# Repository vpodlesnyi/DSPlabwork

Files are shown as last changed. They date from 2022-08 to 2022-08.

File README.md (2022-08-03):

# DSPlabwork
The PCB for Digital Signal Processing classes at the Department of Mechatronics and Robotics.

Technical specifications:
- signal processing from a strain gauge force sensor;
- signal processing from an electret microphone;
- I2C;
- sound generation;
- main MCU ATMega328.

demo image

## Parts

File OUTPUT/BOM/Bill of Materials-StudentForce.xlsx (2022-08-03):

Description | Part Number | Value | Voltage | Designator | Quantity
12-Bit DAC with SPI™ Interface | MCP4921-E/P |  |  | DD1 | 1
Cтабилитрон (лавинный выпрямительный диод) односторонний | SMAJ5.0A-TR |  |  | VD7 | 1
EMI Suppression Filter | BLM18PG181SN1D |  |  | L1 | 1
EMI Suppression Filter | SDR0604-2R2ML | 2,2мкГн |  | L2 | 1
EMI Suppression Filter | CM201212-R18KL | 0,18мкГн |  | L3, L4, L5, L6 | 4
FET-INPUT OPERATIONAL AMPLIFIERS | OPA137PA |  |  | DA2 | 1
Low Cost Low Power Instrumentation Amplifier | AD623ARZ |  |  | DA4 | 1
Low Voltage Audio Power Amplifier | LM386M-1/NOPB |  |  | DA1 | 1
Medium-density performance line ARM®-based 32-bit MCU with 64 or 128 KB Flash, USB, CAN, 7 timers, 2 ADCs, 9 com. interfaces | STM32F103C8T6TR |  |  | DD2 | 1
N-MOSFET | IRLML6401TRPBF |  |  | VT1 | 1
Potentiometer | 3302X-3-103 | 10к |  | R1 | 1
Step-Down DC-DC Converter | LM3671MF-3.3/NOPB |  |  | DA3 | 1
USB UART module cp2102 |  |  |  | U1 | 1
Диод Шоттки | PMEG2010AEB.115 |  |  | VD2, VD3 | 2
Кварцевый резонатор | 8.000MHzHC-49US |  |  | Z1 | 1
Кнопка |  |  |  | S1 | 1
Конденсатор | GRM32ER61A106K | 10мк | 25В | C2 | 1
Конденсатор | GRM31CR71E106KA12L* | 10мк | 25В | C4, C22 | 2
Конденсатор | GRM21BR71H104K** | 0,1мк | 50B | C5 | 1
Конденсатор | GRM21BR71H154K | 0,15мк | 50B | C6 | 1
Конденсатор | GRM216R71H103K | 0,01мк | 50B | C7, C32 | 2
Конденсатор | GRM188R71H104KA93D | 0,1мк | 50B | C8, C9, C10, C12, C13, C14, C15 | 7
Конденсатор | CC0603JRNPO9BN220 | 22 | 50B | C11, C16 | 2
Конденсатор | GRM216R71H122K | 1200 | 50В | C17, C19, C20, C21 | 4
Конденсатор | GRM21BR71C105K | 1мк | 16B | C18 | 1
Конденсатор | GRM21BR71H104KA01L | 0,1мк | 50В | C23, C30, C35 | 3
Конденсатор | GRM21BR61E475KA12L | 4,7мк | 25B | C25 | 1
Конденсатор | GRM1885C1H101J | 100 | 50B | C31, C34 | 2
Конденсатор | GRM188R71H102K | 1000 | 50B | C33 | 1
Конденсатор полярный | ECASD41C106M060K | 10мк | 16В | C1 | 1
Конденсатор полярный | T491D227K016ZT | 220мк | 10B | C3 | 1
Конденсатор полярный | 293D106X9016A2TE3 | 10мк | 16В | C24, C26, C27, C28, C29 | 5
Предохранитель | MF-MSMF075 |  |  | FU1 | 1
Прецезионный источник опорного напряжения | LM4040BIM3-2.5/NOPB |  |  | VD1, VD5 | 2
Разъем - 2 конт. розетка | DS1069-2 MR-A |  |  | X1 | 1
Разъем - 2 конт. розетка | DS1069-2 MR-A |  |  | X4 | 1
Разъем - 2 конт. розетка | DS-210B(PBT)(NB) |  |  | X5 | 1
Разъем - 4 конт. розетка | DS1069-4MRW6SA |  |  | X6 | 1
Разъем - 6 конт. вилка | MPU-9250 |  |  | X3 | 1
Разъем - 6 конт. розетка |  |  |  | X2 | 1
Резистор | RC0805FR-0710RL | 10 |  | R2 | 1
Резистор | RC0603FR-0710KL | 10к |  | R3, R5, R6, R7 | 4
Резистор | RC0603FR-07300RL | 300 |  | R4 | 1
Резистор | RC0805FR-072K3 | 3,3к |  | R8, R9, R10, R11, R12 | 5
Резистор | RC0805FR-0710KL | 10к |  | R13 | 1
Резистор | RC0805FR-070RL | 0 |  | R14, R15, R16, R17 | 4
Резистор | RC0805FR-0730KL | 30к |  | R18 | 1
Резистор | RC0805FR-071KL | 1к |  | R19, R20, R21 | 3
Резистор | RC0805FR-07510RL | 510 |  | R22 | 1

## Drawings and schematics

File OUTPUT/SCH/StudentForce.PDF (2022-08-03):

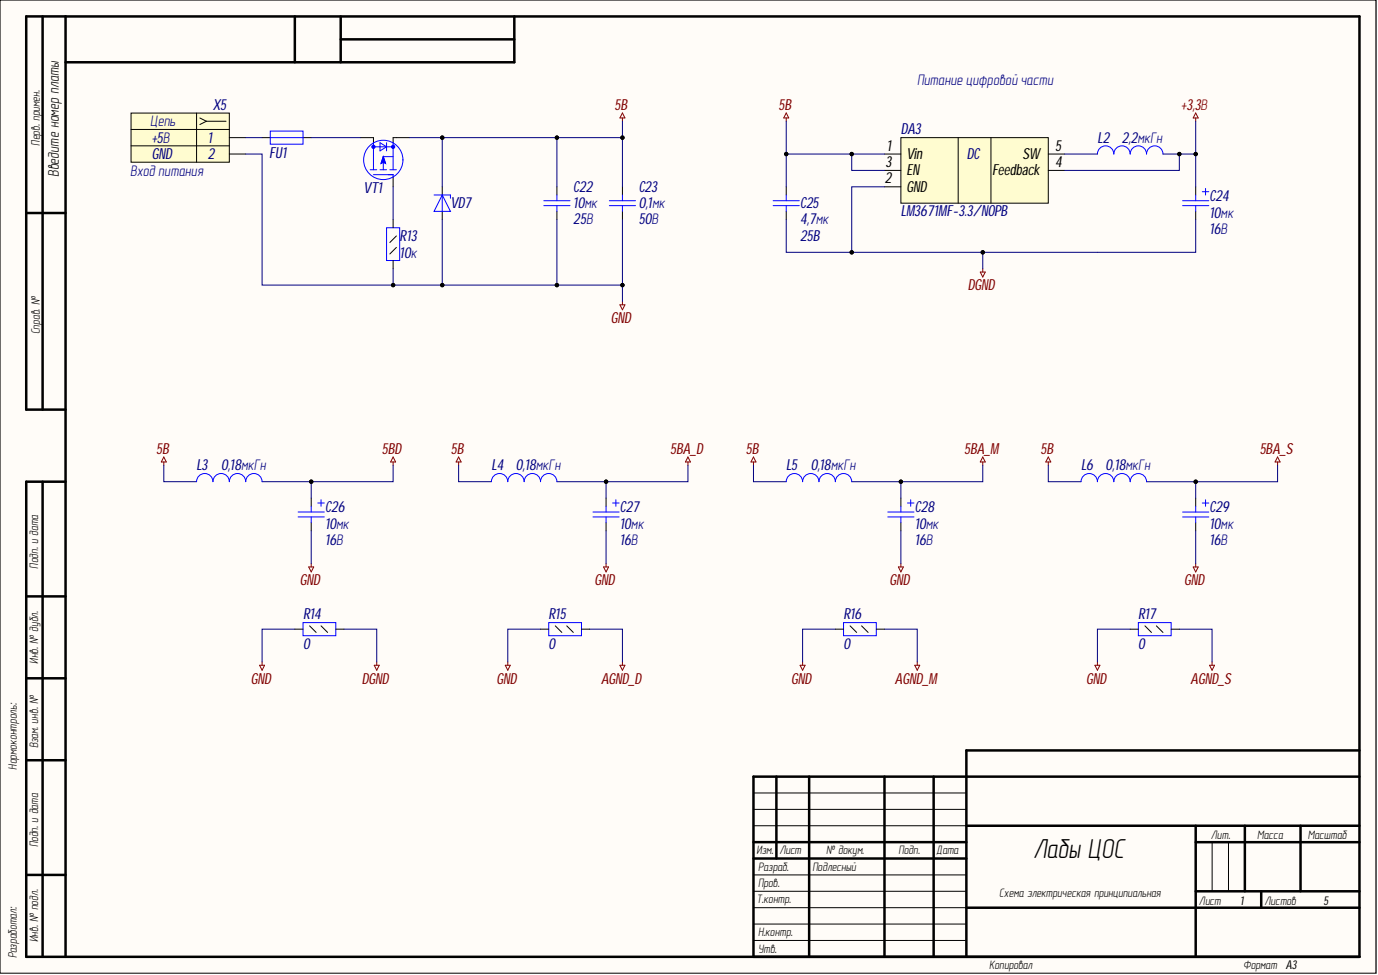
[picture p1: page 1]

Подп. и дата Перв. примен. Справ. №

Цепь
+5В | 1
GND | 2

Vin | Feedback | 4 DC
EN 3

Инв. № подл. Инв. № дубл. Подп. и дата Взам. инв. №

Лабы ЦОС Схема электрическая принципиальная | Лит. | Масса | Масштаб

Изм. | Лист | № докум. | Подп. | Дата
Разраб. | | Подлесный
Пров.
Т.контр. | | | | | Лист | Листов 5

Н.контр.
Утв.

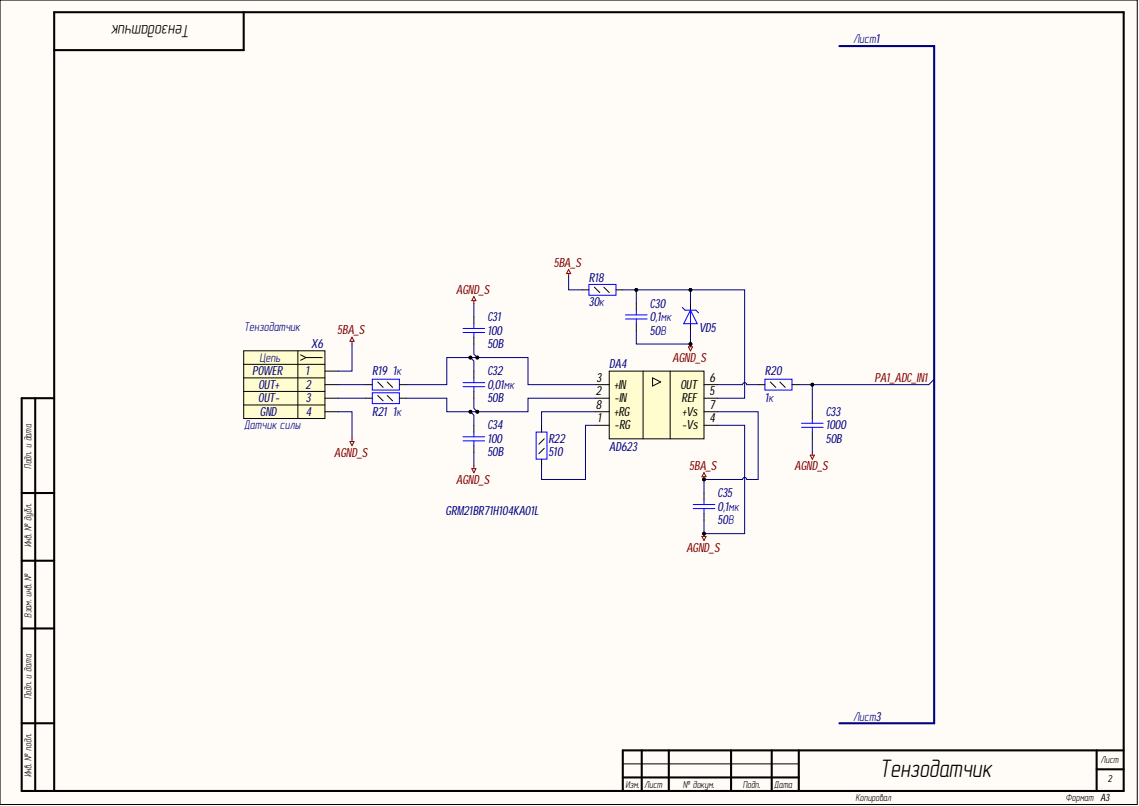
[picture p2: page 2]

Цепь
POWER
OUT+ | 1234

OUT-
GND

в. № подл. Инв. № дубл. Подп. и дата Взам. инв. № Подп. и дата

Тензодатчик

Изм . | Лис т | № докум . | Подп | Дат а

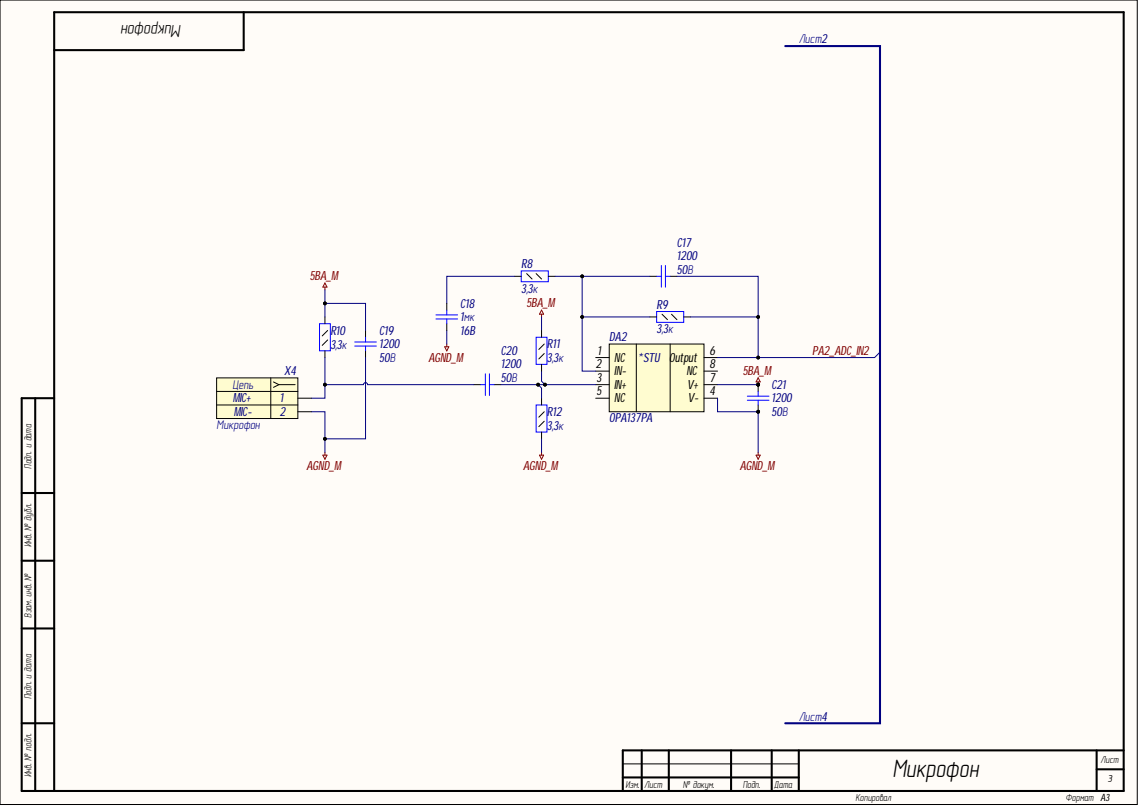
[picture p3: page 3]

Цепь
MIC+ | 12
MIC-

в. № подл. Инв. № дубл. Подп. и дата Взам. инв. № Подп. и дата

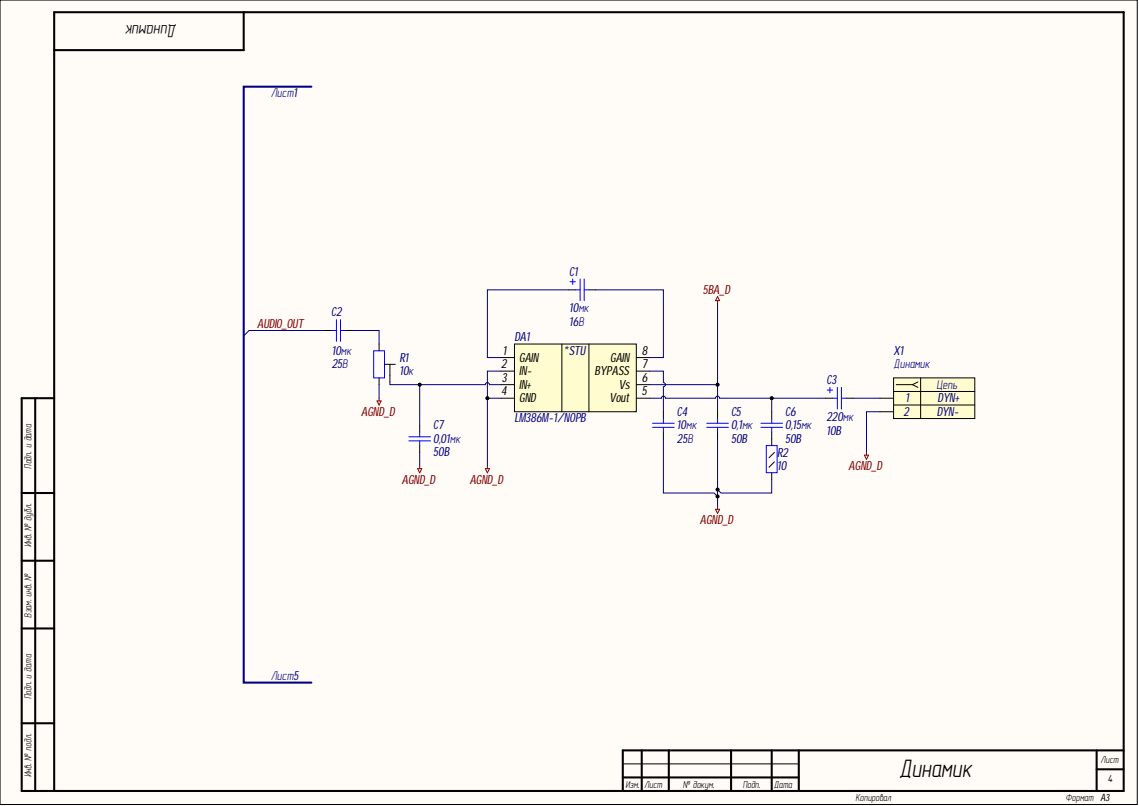
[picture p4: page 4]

IN-IN+ GND | | BYPASS Vs Vout | 7

DYN+
DYN-

в. № подл. Инв. № дубл. Подп. и дата Взам. инв. № Подп. и дата

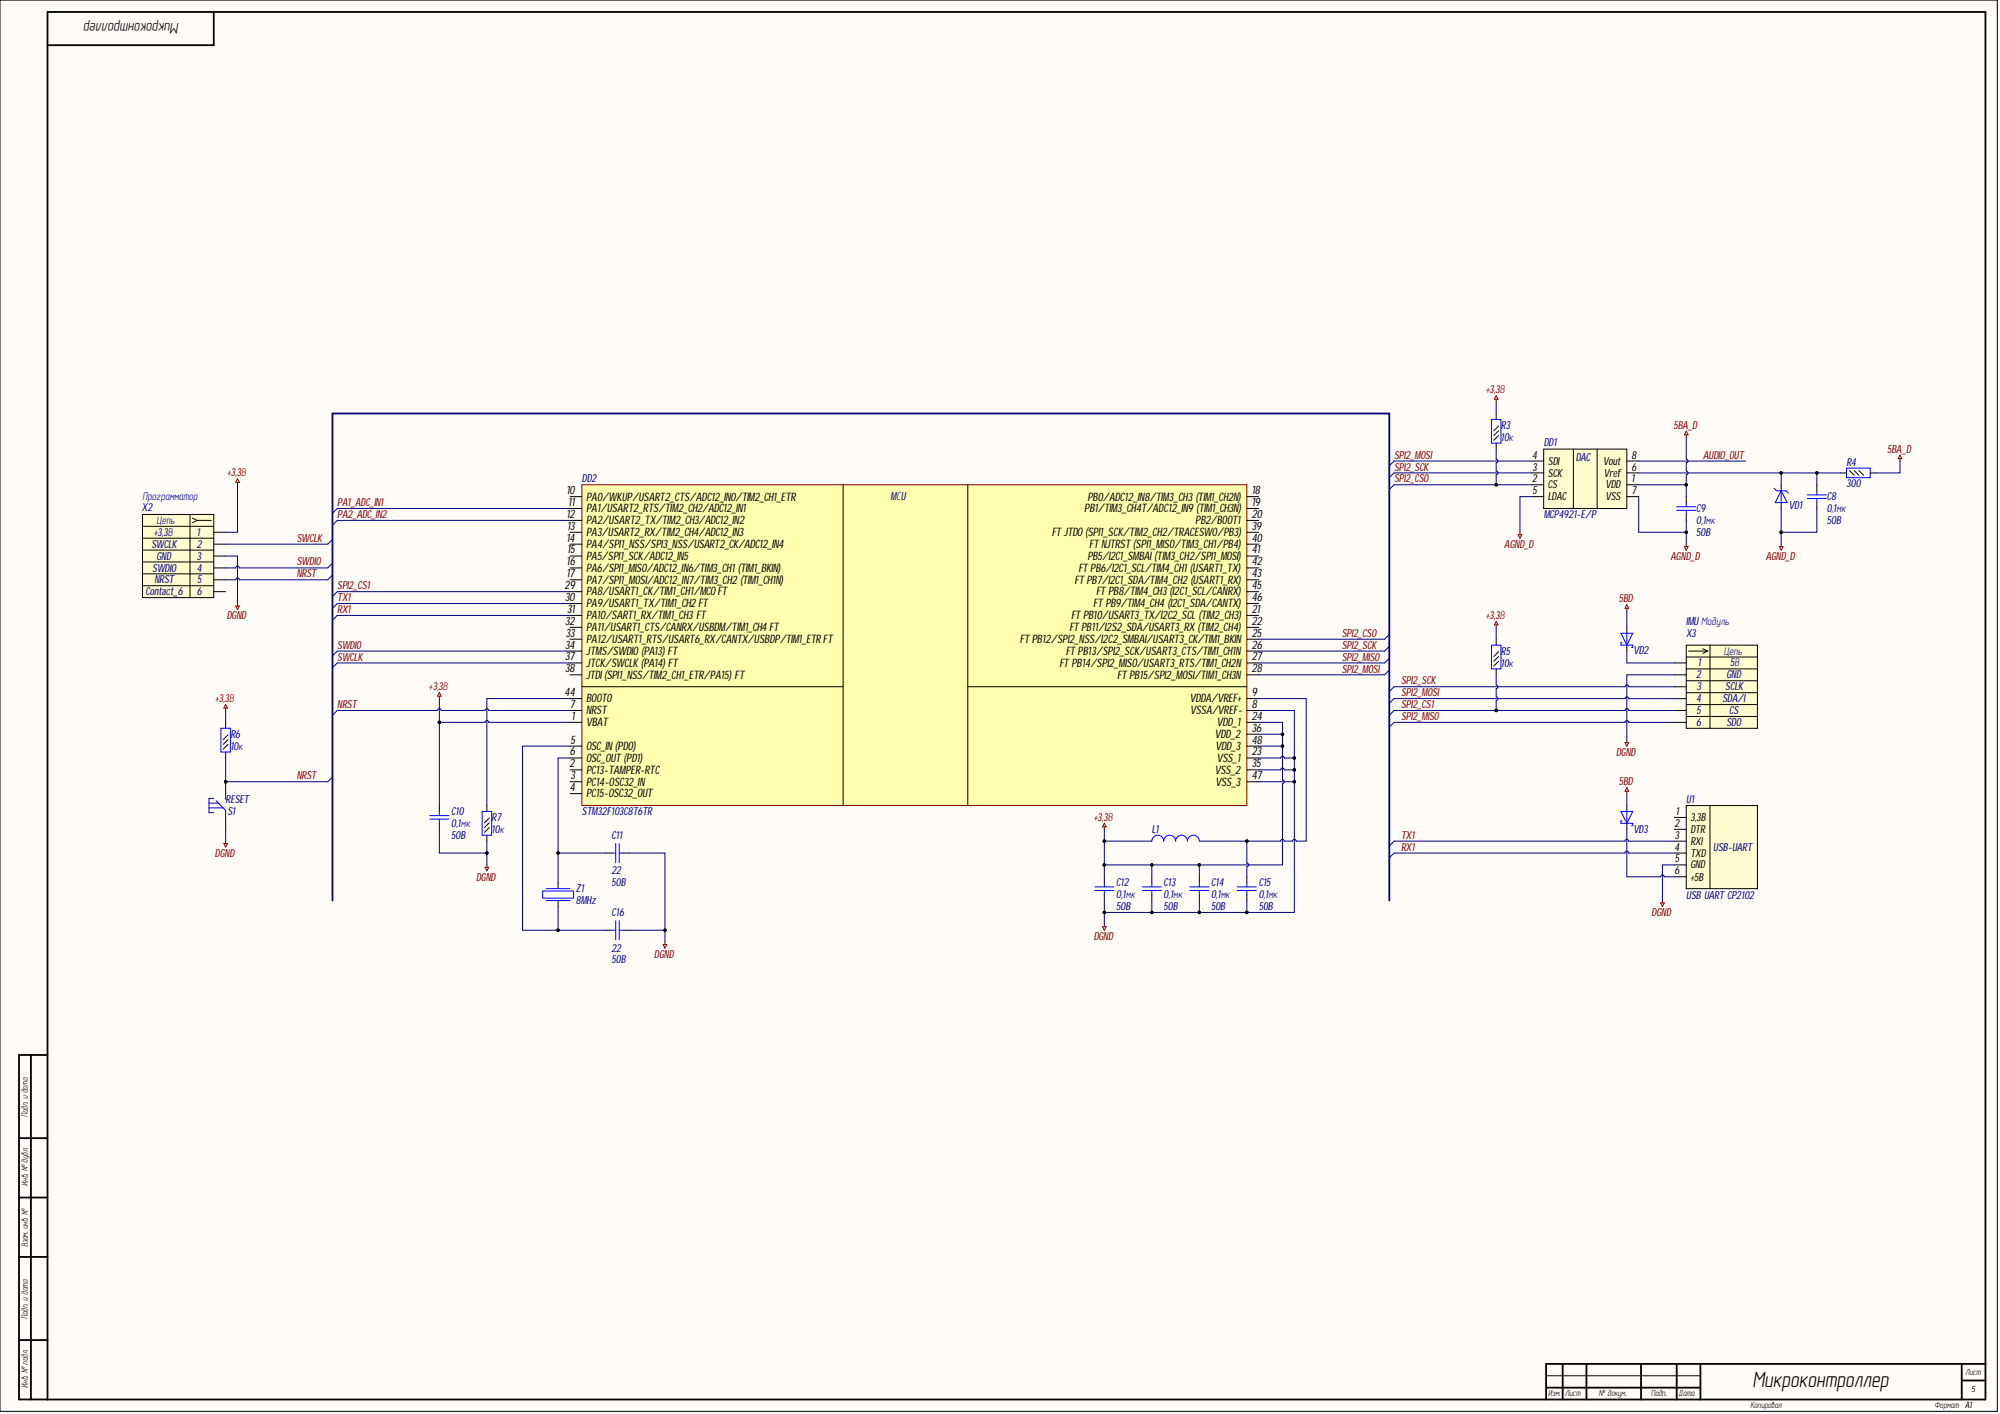
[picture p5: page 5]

Цепь
+3,3В
SWCLK | 1234

GND
SWDIO
NRST | 5
Contact_6 | 6

5В

1234 | GND

BOOT0 44 NRST VBAT OSC_IN (PDO) OSC_OUT (PD1) PC13-TAMPER-RTC PC14-OSC32_IN PC15-OSC32_OUT | VSSA/VREF-VDD_1 VDD_2 VDD_3 VSS_1 VSS_2
1 | 24
5 | 36

SCLK
SDA/I
5 | SDO CS 6

в. № подл. Инв. № дубл. Подп. и дата Взам. инв. № Подп. и дата

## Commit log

2018-10-14 Поместил впервые файлы проекта
    [DynStudent.SchDoc, MCUStudent.SchDoc, MicroStudent.SchDoc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]
2018-10-14 Создал файл READ.me
2018-10-26 Get new file
    [Bill of students-StudentForce.xls, StudentForce.PrjPcb]
2018-10-26 Last commit
    [StudentForce.PrjPcb]
2018-10-26 New file
    [Bill of materials-StudentForce.xls]
2018-11-15 Change values
    [DynStudent.SchDoc, MCUStudent.SchDoc, MicroStudent.SchDoc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]
2018-12-05 поменял номиналы и добавил pdf
    [Bill of materials-StudentForce.xls, MicroStudent.SchDoc, StudentForce.PrjPcb]
2019-02-13 Внести изменения, необ комментарии присутствуют на схеме.
    [DynStudent.SchDoc, MCUStudent.SchDoc, MicroStudent.SchDoc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]
2019-02-13 Внесены основные правки, заменен МК на stm32f103c8t6. Ожидается проверка Василия.
    [DynStudent.SchDoc, MCUStudent.SchDoc, MicroStudent.SchDoc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]
2019-02-14 Одобрено.
    [PowerStudent.SchDoc]
2019-02-14 Заменил резисторы и конденсаторы -> в корпусе 0603.
    [MCUStudent.SchDoc]
2019-02-14 Заменен вывод для гироскопа с i2c на гироскоп с spi.
    [MCUStudent.SchDoc]
2019-02-14 Проставил номиналы элементов
    [DynStudent.SchDoc, MCUStudent.SchDoc, MicroStudent.SchDoc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]
2019-02-14 Исправлена цепь NRST, заменена кнопка на однопозиционную.
    [MCUStudent.SchDoc]
2019-02-18 Обвязка для тензодатчика готова, нид аппрувед!
    [StudentForce.PrjPcb]
2019-02-18 Пофиксил цепь кнопки Reset (NetLabel RESET->NRST).
    [MCUStudent.SchDoc]
2019-02-18 Заменил конденсаторы (у танталового не было фудпринта).
    [PowerStudent.SchDoc]
2019-02-18 поправил тензодатчик
    [StudentForce.PcbDoc, StudentForce.PrjPcb]
2019-02-23 Микрофон и динамик сделаны.
    [MicroStudent.SchDoc, StudentForce.PcbDoc]
2019-02-23 попроавил 24.02
    [DynStudent.SchDoc, MCUStudent.SchDoc, MicroStudent.SchDoc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]
2019-02-27 Проложить дорожки необ.
    [MCUStudent.SchDoc, PowerStudent.SchDoc, StudentForce.PcbDoc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]
2019-02-27 Заменил операционный усилитель у микрофона.
    [MicroStudent.SchDoc]
2019-02-27 Заменил разъем для USB UART преобразователя.
    [MCUStudent.SchDoc]
2019-02-27 Продолжаем трассировку.
    [StudentForce.PcbDoc, StudentForce.PrjPcb]
2019-02-28 Поменял фудпринт USB UART, теперь точно годный.
    [MCUStudent.SchDoc]
2019-02-28 Нид хелп!
    [StudentForce.PcbDoc]
2019-03-01 Поменял катушку L2: была на 50мА, теперь на 2,8А вроде.
    [PowerStudent.SchDoc]
2019-03-01 Дотрассировал. Сделал без полигона на +3,3В - теперь толстая шина.
    [StudentForce.PcbDoc, StudentForce.PrjPcb]
2019-03-01 Все отлично!
    [StudentForce.PcbDoc, StudentForce.PrjPcb]
2019-03-08 Теперь все компоненты привязаеы к библиотеке.
    [DynStudent.SchDoc, MCUStudent.SchDoc, MicroStudent.SchDoc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]
2019-03-08 Bill of materials file.
    [BOM_DSPlabwork_with_Designator.xls, BOM_DSPlabwork_without_Designator.xls, Bill of materials-StudentForce.xls]
2019-03-08 Поправил название УГО IMU модуля.
    [MCUStudent.SchDoc]
2019-03-08 Практически закончил, осталось три нерешенных компонента. Вася, порешай!
    [BOM_DSPlabwork_with_Designator.xls]
2019-03-09 1. 293D107X9016D2TE3-такой кондер 2. кнопку вставил 3. будет резистор 510
    [BOM_DSPlabwork_with_Designator.xls, TensoStudent.SchDoc]
2022-08-03 Reorganised files structure
    [BOM_DSPlabwork_with_Designator.xls, BOM_DSPlabwork_without_Designator.xls, Bill of Materials-StudentForce.xlsx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]
